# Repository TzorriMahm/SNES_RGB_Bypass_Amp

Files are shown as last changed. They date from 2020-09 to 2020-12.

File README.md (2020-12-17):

# SNES RGB Bypass Amp
**A modding board to bypass the SNES' video encoder by using TI's THS7374 video amplifier, to achieve optimised RGB video.**<br>

This modification works with all 1-Chip models (PAL/NTSC).

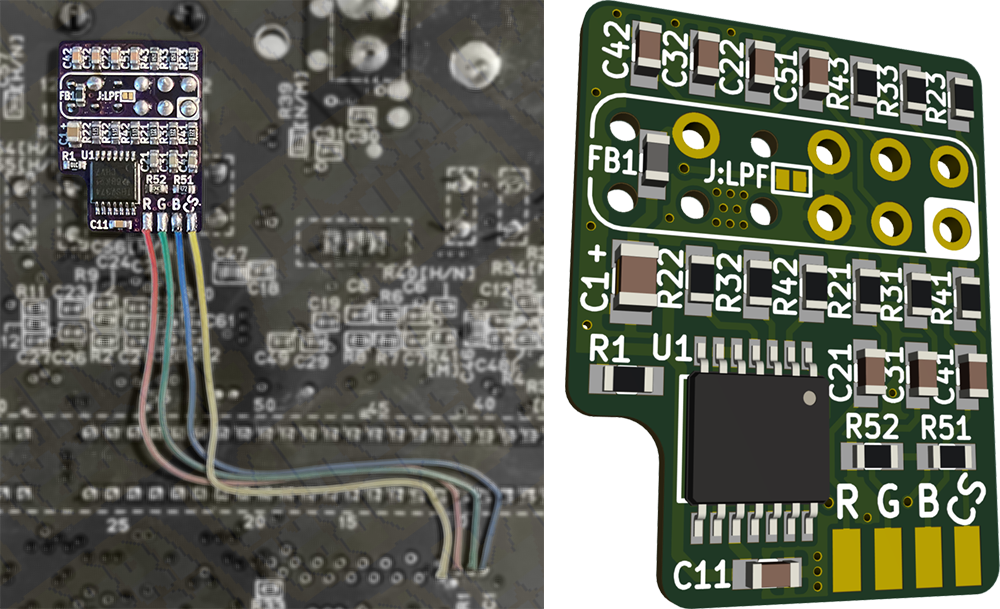
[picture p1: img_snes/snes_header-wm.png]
Header image

<br><br>
**⁓ Designed with ♥ in Germany ⁓**<br><br>
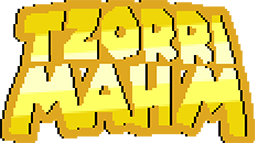
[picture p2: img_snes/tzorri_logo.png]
TzorriMahm

# Where to get the PCB?
You can order the PCB directly from [OSHPark](https://oshpark.com/shared_projects/o16zk0W4).
Of course, feel free to use the gerber files with any manufacturer of your choice.<br>
Use 0.8mm board thickness to ensure an easy and clean installation.

# Before you start
Make sure that your console is a 1-Chip model. If your console is a SNES2/Mini/Jr., this is the case by default.<br>
Otherwise, this can easily done by looking for an indicator at the main board:

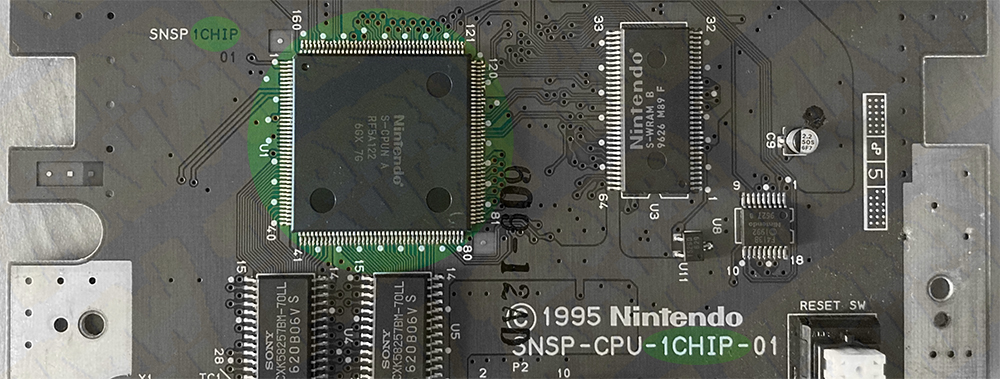
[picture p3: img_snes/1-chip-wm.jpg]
1-CHIP


# Install instructions
## PAL consoles (SNSP-001)
### Preparing the SNES main board
**1-CHIP-01/02 models**
- disconnect +12V from MultiOut Pin 3: **remove R28**
- disconnect stock RGB: **remove R15, R16, R17**
- remove decoupling caps from MultiOut (optional**¹**): **remove C44, C45, C46, C47**

### Installing the modding board
- isolate the bottom side of the modding board to avoid any shorts
- solder the modding board onto the pins of the MultiOut
- solder a wire from the via next to R6 (SNES main board) to pad 'R' (modding board)
- solder a wire from the via next to R7 (SNES main board) to pad 'G' (modding board)
- solder a wire from the via next to R8 (SNES main board) to pad 'B' (modding board)  
- solder a wire from the via that is nearest the bottom left corner of designator C6 (SNES main board) to pad 'CS' (modding board)  

### Install diagram (PAL 1-CHIP)
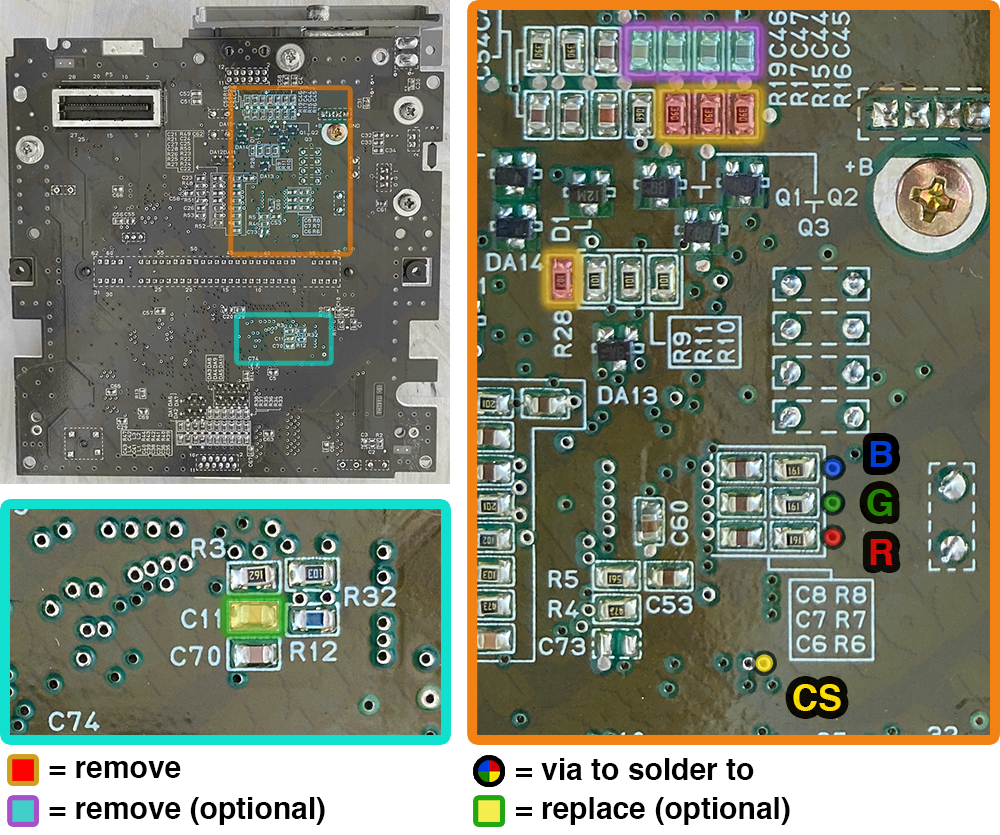
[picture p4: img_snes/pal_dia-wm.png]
PAL install diagram


## NTSC consoles (SNS-001/SHVC-001)
### Preparing the SNES main board
**1-CHIP-01/02 models**<br>
These models already have C-Sync connected to pin 3 of the MultiOut.<br>
You can either use this (not recommended) or:
- disconnect C-Sync from MultiOut Pin 3: **remove R12** (optionally **remove R9, R10, R11, Q1** as well)
- disconnect stock RGB: **remove R15, R16, R17**
- remove decoupling caps from MultiOut (optional**¹**): **remove C44, C45, C46, C47**

**1-CHIP-03 model**<br>
This model hasn't C-Sync connected at all, so you'll have nothing to do here.
- disconnect stock RGB:	**remove R15, R16, R17**
- remove decoupling caps from MultiOut (optional**¹**'**²**):	**remove C44, C45, C47**

### Installing the modding board
- isolate the bottom side of the modding board to avoid any shorts
- solder the modding board onto the pins of the MultiOut
- solder a wire from the via next to R6 (SNES main board) to pad 'R' (modding board)
- solder a wire from the via next to R7 (SNES main board) to pad 'G' (modding board)
- solder a wire from the via next to R8 (SNES main board) to pad 'B' (modding board) 
- solder a wire from the via under the left pad of R9 (SNES main board) to pad 'CS' (modding board)

### Install diagram (NTSC 1-CHIP)
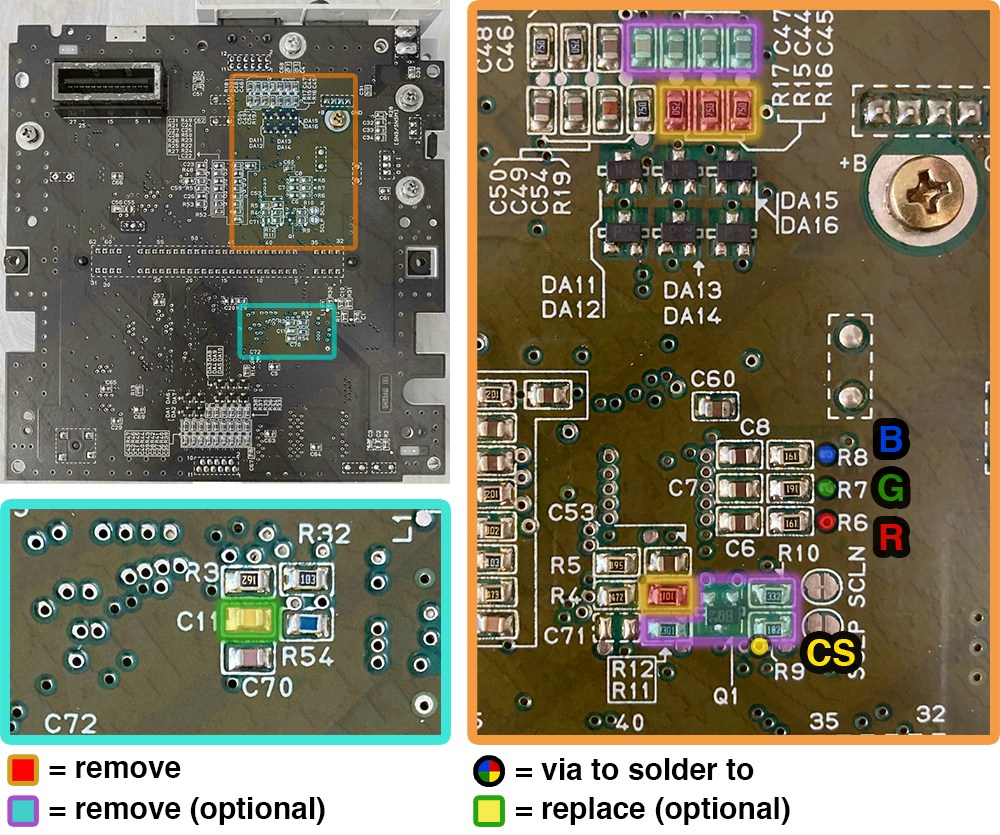
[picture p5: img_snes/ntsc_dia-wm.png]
NTSC install diagram


## NTSC model 2 / SNES2/Mini/Jr. (SNS-101/SHVC-101)
### Preparing the SNES main board
**SNN-CPU-01 model**<br>
Since this model doesn't have stock RGB, here is no preparation needed.

### Installing the modding board
- isolate the bottom side of the modding board to avoid any shorts
- solder the modding board onto the pins of the MultiOut
- solder wires from the vias (shown in the install diagram below) to the appropriate pads on the modding board

### Install diagram (SNES2/Mini/Jr.)
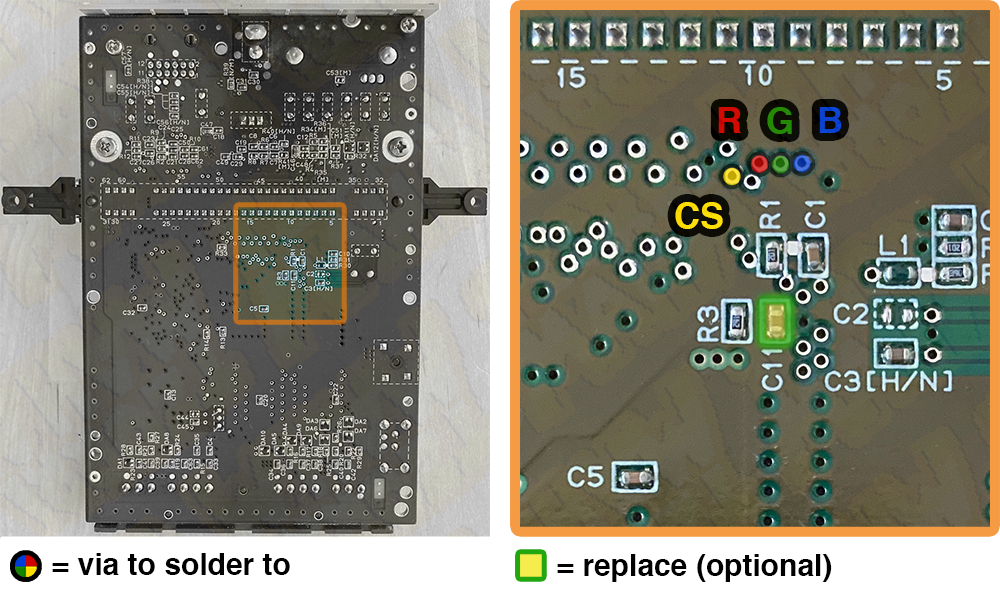
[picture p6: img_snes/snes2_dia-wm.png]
SNES2 install diagram


### Notes
**¹** if you remove the decoupling caps at the MultiOut, make sure to occupy C22, C32, C42 & C51 on the modding board! Never use both at the same time!<br>
**²** if you leave the decoupling caps at the MultiOut, make sure to occupy **at least** C51 on the modding board! (1-CHIP-03 only!) 

# Troubleshooting
Double-check continuity between connections:
- 'R' (modding board) ⇄ S-CPUN pin 156 / S-RGB pin 5 (SNES main board)
- 'G' (modding board) ⇄ S-CPUN pin 157 / S-RGB pin 3 (SNES main board)
- 'B' (modding board) ⇄ S-CPUN pin 158 / S-RGB pin 1 (SNES main board)
- 'CS' (modding board) ⇄ S-CPUN pin 151 / S-RGB pin 7 (SNES main board)

# Miscellaneous
#### Jumper 'J:LPF'
The THS7374 has a low pass filter on each of the four channels which can be turned on by shorting jumper 'J:LPF' on the modding board. This is mostly needed if you wire the console directly to a flat-screen TV. There's no need for the low pass filter on analogue devices.<br>
If you use an OSSC or a Framemeister, it's better to use their filter options.

#### Ghosting fix
In order to get rid of the ghosting issue (which 1-Chip models are known for), simply replace C11 (SNES main board) by a 470nF ceramic capacitor (0805 for normal/fat models, 0603 for SNES2/Mini/Jr.).

#### RGB cable
You will need a RGB cable with 220µF electrolytic capacitors on each of the 'R', 'G' & 'B' lines. The positive end is facing towards the console.<br>
This modding board is designed to output TTL level C-Sync directly at the MultiOut of the console.<br>
With that in mind, make sure you're using a suitable cable with a 470Ω resistor on the sync line to use it with most consumer products (like TV's, OSSC, Framemeister)!

# Disclaimer
I am not responsible for any damage to you, your devices or anything else!<br>
If you do the modification, you do it at your own risk and responsibility!

# Acknowledgement
Most of the credits should go to [borti4938](https://github.com/borti4938). He has made the actual (slightly different) circuit and inspired me to design this board. Thanks man! Thanks to Voultar for research and findig the ghosting fix! Thanks Bob, for your awesome and informative website [RetroRGB](http://retrorgb.com)!<br>
And of course, thanks to the whole retro gaming community for keeping the spirit alive!

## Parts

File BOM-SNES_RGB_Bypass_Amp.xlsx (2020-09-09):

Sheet: Normal, fat model
SNES RGB Bypass Amp - Bill of Materials
for normal/fat models
Designator | Mfr. No | Quantity | Description | Package | Value | Mouser
U1 | THS7374IPWR | 1 | 4-Ch. SD Video Amp | TSSOP-14 |  | https://www.mouser.de/ProductDetail/Texas-Instruments/THS7374IPWR?qs=qU0TI%2FZyA%252BxCw%252BZ%2FnXjpBw%3D%3D
C1 | 08053D226MAT2A | 1 | Ceramic capacitor; X5R; 25V | SMD0805 | 22µF / 20% | https://www.mouser.de/ProductDetail/AVX/08053D226MAT2A?qs=bxXxiBiblXqtZp79ClJbtg%3D%3D
C11 | 06035C104KAT2A | 1 | Ceramic capacitor; X7R; 50V | SMD0603 | 100nF / 10% | https://www.mouser.de/ProductDetail/AVX/06035C104KAT2A?qs=wORnlwVG%2F0dQ8Y%2FnMEnCGg%3D%3D
C21, C31, C31 | 0603YC823KAT2A | 3 | Ceramic capacitor; X7R; 16V | SMD0603 | 82nF / 10% | https://www.mouser.de/ProductDetail/AVX/0603YC823KAT2A?qs=Gc704lYbI0w4J5zALMwFzw%3D%3D
C22, C32, C42, C51 | 0603YC470KAT2A | 4 | Ceramic capacitor; X7R, 16V | SMD0603 | 47pF / 10% | https://www.mouser.de/ProductDetail/AVX/0603YC470KAT2A?qs=EU6FO9ffTwcFkDrBSOUNAw%3D%3D
FB1 | MPZ1608S221ATA00 | 1 | Ferrite bead; power line | SMD0603 |  | https://www.mouser.de/ProductDetail/TDK/MPZ1608S221ATA00
R1 | RC0603FR-0710KL | 1 | Resistor; 1/10W | SMD0603 | 10kΩ / 1% | https://www.mouser.de/ProductDetail/Yageo/RC0603FR-0710KL?qs=grNVn54RoB%252B3GtjbJj3wJQ%3D%3D
R21, R31, R41 | RC0603FR-07750RL | 3 | Resistor; 1/10W | SMD0603 | 750Ω / 1% | https://www.mouser.de/ProductDetail/Yageo/RC0603FR-07750RL?qs=FHALIGSka6kXmIWmb0xdTA%3D%3D
R22, R32, R42 | RC0603FR-075M1L | 3 | Resistor; 1/10W | SMD0603 | 5.1MΩ / 1% | https://www.mouser.de/ProductDetail/Yageo/RC0603FR-075M1L
R23, R33, R43 | RC0603FR-0775RL | 3 | Resistor; 1/10W | SMD0603 | 75Ω / 1% | https://www.mouser.de/ProductDetail/Yageo/RC0603FR-0775RL
R51 | RC0603FR-074K99L | 1 | Resistor; 1/10W | SMD0603 | 4.99kΩ / 1% | https://www.mouser.de/ProductDetail/Yageo/RC0603FR-074K99L
R52 | RC0603FR-074K3L | 1 | Resistor; 1/10W | SMD0603 | 4.3kΩ / 1% | https://www.mouser.de/ProductDetail/Yageo/RC0603FR-074K3L
Mouser Basket: | https://www.mouser.de/ProjectManager/ProjectDetail.aspx?AccessID=b03722a6a4

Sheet: Normal, fat model + DeJitter
SNES RGB Bypass Amp - Bill of Materials
for normal/fat models with DeJitter mod installed
Designator | Mfr. No | Quantity | Description | Package | Value | Mouser
U1 | THS7374IPWR | 1 | 4-Ch. SD Video Amp | TSSOP-14 |  | https://www.mouser.de/ProductDetail/Texas-Instruments/THS7374IPWR?qs=qU0TI%2FZyA%252BxCw%252BZ%2FnXjpBw%3D%3D
C1 | 08053D226MAT2A | 1 | Ceramic capacitor; X5R; 25V | SMD0805 | 22µF / 20% | https://www.mouser.de/ProductDetail/AVX/08053D226MAT2A?qs=bxXxiBiblXqtZp79ClJbtg%3D%3D
C11 | 06035C104KAT2A | 1 | Ceramic capacitor; X7R; 50V | SMD0603 | 100nF / 10% | https://www.mouser.de/ProductDetail/AVX/06035C104KAT2A?qs=wORnlwVG%2F0dQ8Y%2FnMEnCGg%3D%3D
C21, C31, C31 | 0603YC823KAT2A | 3 | Ceramic capacitor; X7R; 16V | SMD0603 | 82nF / 10% | https://www.mouser.de/ProductDetail/AVX/0603YC823KAT2A?qs=Gc704lYbI0w4J5zALMwFzw%3D%3D
C22, C32, C42, C51 | 0603YC470KAT2A | 4 | Ceramic capacitor; X7R, 16V | SMD0603 | 47pF / 10% | https://www.mouser.de/ProductDetail/AVX/0603YC470KAT2A?qs=EU6FO9ffTwcFkDrBSOUNAw%3D%3D
FB1 | MPZ1608S221ATA00 | 1 | Ferrite bead; power line | SMD0603 |  | https://www.mouser.de/ProductDetail/TDK/MPZ1608S221ATA00
R1 | RC0603FR-0710KL | 1 | Resistor; 1/10W | SMD0603 | 10kΩ / 1% | https://www.mouser.de/ProductDetail/Yageo/RC0603FR-0710KL?qs=grNVn54RoB%252B3GtjbJj3wJQ%3D%3D
R21, R31, R41 | RC0603FR-07750RL | 3 | Resistor; 1/10W | SMD0603 | 750Ω / 1% | https://www.mouser.de/ProductDetail/Yageo/RC0603FR-07750RL?qs=FHALIGSka6kXmIWmb0xdTA%3D%3D
R22, R32, R42 | RC0603FR-075M1L | 3 | Resistor; 1/10W | SMD0603 | 5.1MΩ / 1% | https://www.mouser.de/ProductDetail/Yageo/RC0603FR-075M1L
R23, R33, R43 | RC0603FR-0775RL | 3 | Resistor; 1/10W | SMD0603 | 75Ω / 1% | https://www.mouser.de/ProductDetail/Yageo/RC0603FR-0775RL
R51 | RC0603FR-074K7L | 1 | Resistor; 1/10W | SMD0603 | 4.7kΩ / 1% | https://www.mouser.de/ProductDetail/Yageo/RC0603FR-074K7L
R52 | RC0603FR-0710K7L | 1 | Resistor; 1/10W | SMD0603 | 10.7kΩ / 1% | https://www.mouser.de/ProductDetail/Yageo/RC0603FR-0710K7L
Mouser Basket | https://www.mouser.de/ProjectManager/ProjectDetail.aspx?AccessID=d139a54297

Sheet: SNES2-Mini-Jr.
SNES RGB Bypass Amp - Bill of Materials
for SNES2/Mini/Jr. model
Designator | Mfr. No | Quantity | Description | Package | Value | Mouser
U1 | THS7374IPWR | 1 | 4-Ch. SD Video Amp | TSSOP-14 |  | https://www.mouser.de/ProductDetail/Texas-Instruments/THS7374IPWR?qs=qU0TI%2FZyA%252BxCw%252BZ%2FnXjpBw%3D%3D
C1 | 08053D226MAT2A | 1 | Ceramic capacitor; X5R; 25V | SMD0805 | 22µF / 20% | https://www.mouser.de/ProductDetail/AVX/08053D226MAT2A?qs=bxXxiBiblXqtZp79ClJbtg%3D%3D
C11 | 06035C104KAT2A | 1 | Ceramic capacitor; X7R; 50V | SMD0603 | 100nF / 10% | https://www.mouser.de/ProductDetail/AVX/06035C104KAT2A?qs=wORnlwVG%2F0dQ8Y%2FnMEnCGg%3D%3D
C21, C31, C31 | 0603YC823KAT2A | 3 | Ceramic capacitor; X7R; 16V | SMD0603 | 82nF / 10% | https://www.mouser.de/ProductDetail/AVX/0603YC823KAT2A?qs=Gc704lYbI0w4J5zALMwFzw%3D%3D
C22, C32, C42, C51 | 0603YC470KAT2A | 4 | Ceramic capacitor; X7R, 16V | SMD0603 | 47pF / 10% | https://www.mouser.de/ProductDetail/AVX/0603YC470KAT2A?qs=EU6FO9ffTwcFkDrBSOUNAw%3D%3D
FB1 | MPZ1608S221ATA00 | 1 | Ferrite bead; power line | SMD0603 |  | https://www.mouser.de/ProductDetail/TDK/MPZ1608S221ATA00
R1 | RC0603FR-0710KL | 1 | Resistor; 1/10W | SMD0603 | 10kΩ / 1% | https://www.mouser.de/ProductDetail/Yageo/RC0603FR-0710KL?qs=grNVn54RoB%252B3GtjbJj3wJQ%3D%3D
R21, R31, R41 | RC0603FR-071K2L | 3 | Resistor; 1/10W | SMD0603 | 1.2kΩ / 1% | https://www.mouser.de/ProductDetail/Yageo/RC0603FR-071K2L?qs=VU8sRB4EgwBLEnKW6KYjqA%3D%3D
R22, R32, R42 | RC0603FR-075M1L | 3 | Resistor; 1/10W | SMD0603 | 5.1MΩ / 1% | https://www.mouser.de/ProductDetail/Yageo/RC0603FR-075M1L
R23, R33, R43 | RC0603FR-0775RL | 3 | Resistor; 1/10W | SMD0603 | 75Ω / 1% | https://www.mouser.de/ProductDetail/Yageo/RC0603FR-0775RL
R51 | RC0603FR-074K99L | 1 | Resistor; 1/10W | SMD0603 | 4.99kΩ / 1% | https://www.mouser.de/ProductDetail/Yageo/RC0603FR-074K99L
R52 | RC0603FR-074K3L | 1 | Resistor; 1/10W | SMD0603 | 4.3kΩ / 1% | https://www.mouser.de/ProductDetail/Yageo/RC0603FR-074K3L
Mouser Basket: | https://www.mouser.de/ProjectManager/ProjectDetail.aspx?AccessID=137eea1f68

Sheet: SNES2-Mini-Jr. + DeJitter
SNES RGB Bypass Amp - Bill of Materials
for SNES2/Mini/Jr. model with DeJitter mod installed
Designator | Mfr. No | Quantity | Description | Package | Value | Mouser
U1 | THS7374IPWR | 1 | 4-Ch. SD Video Amp | TSSOP-14 |  | https://www.mouser.de/ProductDetail/Texas-Instruments/THS7374IPWR?qs=qU0TI%2FZyA%252BxCw%252BZ%2FnXjpBw%3D%3D
C1 | 08053D226MAT2A | 1 | Ceramic capacitor; X5R; 25V | SMD0805 | 22µF / 20% | https://www.mouser.de/ProductDetail/AVX/08053D226MAT2A?qs=bxXxiBiblXqtZp79ClJbtg%3D%3D
C11 | 06035C104KAT2A | 1 | Ceramic capacitor; X7R; 50V | SMD0603 | 100nF / 10% | https://www.mouser.de/ProductDetail/AVX/06035C104KAT2A?qs=wORnlwVG%2F0dQ8Y%2FnMEnCGg%3D%3D
C21, C31, C31 | 0603YC823KAT2A | 3 | Ceramic capacitor; X7R; 16V | SMD0603 | 82nF / 10% | https://www.mouser.de/ProductDetail/AVX/0603YC823KAT2A?qs=Gc704lYbI0w4J5zALMwFzw%3D%3D
C22, C32, C42, C51 | 0603YC470KAT2A | 4 | Ceramic capacitor; X7R, 16V | SMD0603 | 47pF / 10% | https://www.mouser.de/ProductDetail/AVX/0603YC470KAT2A?qs=EU6FO9ffTwcFkDrBSOUNAw%3D%3D
FB1 | MPZ1608S221ATA00 | 1 | Ferrite bead; power line | SMD0603 |  | https://www.mouser.de/ProductDetail/TDK/MPZ1608S221ATA00
R1 | RC0603FR-0710KL | 1 | Resistor; 1/10W | SMD0603 | 10kΩ / 1% | https://www.mouser.de/ProductDetail/Yageo/RC0603FR-0710KL?qs=grNVn54RoB%252B3GtjbJj3wJQ%3D%3D
R21, R31, R41 | RC0603FR-071K2L | 3 | Resistor; 1/10W | SMD0603 | 1.2kΩ / 1% | https://www.mouser.de/ProductDetail/Yageo/RC0603FR-071K2L?qs=VU8sRB4EgwBLEnKW6KYjqA%3D%3D
R22, R32, R42 | RC0603FR-075M1L | 3 | Resistor; 1/10W | SMD0603 | 5.1MΩ / 1% | https://www.mouser.de/ProductDetail/Yageo/RC0603FR-075M1L
R23, R33, R43 | RC0603FR-0775RL | 3 | Resistor; 1/10W | SMD0603 | 75Ω / 1% | https://www.mouser.de/ProductDetail/Yageo/RC0603FR-0775RL
R51 | RC0603FR-074K7L | 1 | Resistor; 1/10W | SMD0603 | 4.7kΩ / 1% | https://www.mouser.de/ProductDetail/Yageo/RC0603FR-074K7L
R52 | RC0603FR-0710K7L | 1 | Resistor; 1/10W | SMD0603 | 10.7kΩ / 1% | https://www.mouser.de/ProductDetail/Yageo/RC0603FR-0710K7L
Mouser Basket: | https://www.mouser.de/ProjectManager/ProjectDetail.aspx?AccessID=aa5ca245f8

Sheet: Ghosting fix
Ghosting fix (optional)
(replace capacitor on SNES main board)
Designator (SNES) | Mfr. No | Quantity | Description | Package | Value | Note | Mouser
C11 | 0805YC474KAT2A | 1 | Ceramic capacitor; X7R, 16V | SMD0805 | 470nF / 10% | for normal/fat model | https://www.mouser.de/ProductDetail/AVX/0805YC474KAT2A?qs=x%2FgdHuCDerNY43ALHLz9VA%3D%3D
C11 | 0603YC474KAT2A | 1 | Ceramic capacitor; X7R, 16V | SMD0603 | 470nF / 10% | for SNES2/Mini/Jr. | https://www.mouser.de/ProductDetail/AVX/0603YC474KAT2A

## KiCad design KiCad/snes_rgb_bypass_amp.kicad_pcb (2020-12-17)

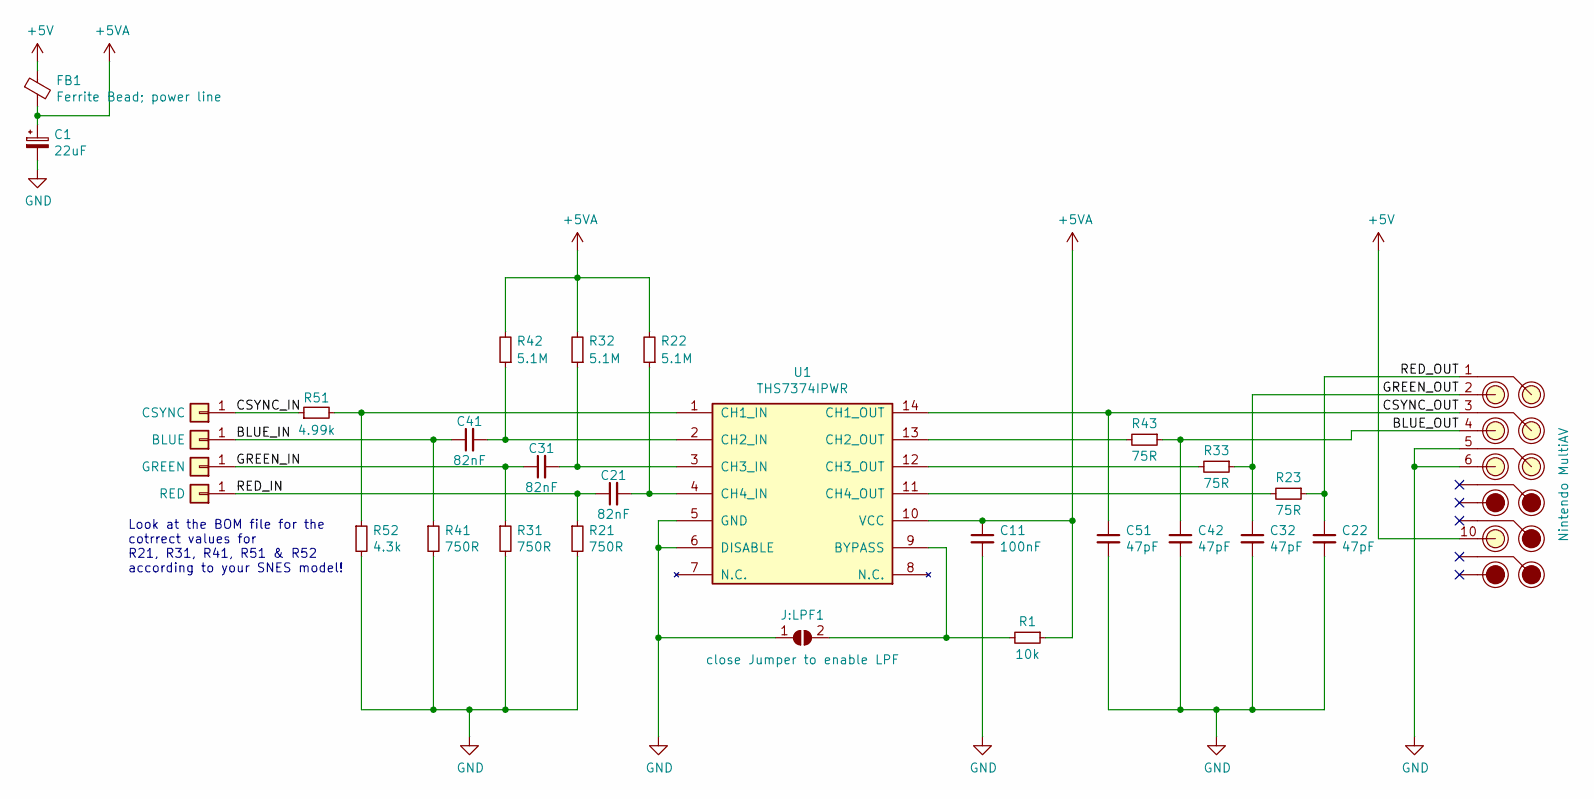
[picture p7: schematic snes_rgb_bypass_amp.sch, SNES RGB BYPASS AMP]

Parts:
C1: 22uF; C_SMD0805
C11: 100nF; C_SMD0603
C21, C31, C41: 82nF; C_SMD0603
C22, C32, C42, C51: 47pF; C_SMD0603
FB1: Ferrite Bead; power line; FB_SMD0603
INPUT_1: RED; SolderPad_customizable
INPUT_2: GREEN; SolderPad_customizable
INPUT_3: BLUE; SolderPad_customizable
INPUT_4: CSYNC; SolderPad_customizable
J:LPF1: close Jumper to enable LPF; SolderJumper_2x0.5x0.75mm
MultiAV1: Nintendo MultiAV; NintendoMultiAV_FB-gap
R1: 10k; R_SMD0603
R21, R31, R41: 750R; R_SMD0603
R22, R32, R42: 5.1M; R_SMD0603
R23, R33, R43: 75R; R_SMD0603
R51: 4.99k; R_SMD0603
R52: 4.3k; R_SMD0603
U1: THS7374IPWR; TSSOP-14

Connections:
+5V: FB1.1, MultiAV1.10
+5VA: C1.1, C11.1, FB1.2, R1.1, R22.2, R32.2, R42.2, U1.10 (VCC)
/BLUE_IN: C41.1, INPUT_3.1, R41.1
/BLUE_OUT: C42.1, MultiAV1.4, R43.1
/CSYNC_IN: INPUT_4.1, R51.1
/CSYNC_OUT: C51.1, MultiAV1.3, U1.14 (CH1_OUT)
/GREEN_IN: C31.1, INPUT_2.1, R31.1
/GREEN_OUT: C32.1, MultiAV1.2, R33.1
/RED_IN: C21.1, INPUT_1.1, R21.1
/RED_OUT: C22.1, MultiAV1.1, R23.1
GND: C1.2, C11.2, C22.2, C32.2, C42.2, C51.2, J:LPF1.1 (A), MultiAV1.5, MultiAV1.6, R21.2, R31.2, R41.2, R52.2, U1.5 (GND), U1.6 (DISABLE)
unnamed: C21.2, R22.1, U1.4 (CH4_IN)
unnamed: C31.2, R32.1, U1.3 (CH3_IN)
unnamed: C41.2, R42.1, U1.2 (CH2_IN)
unnamed: J:LPF1.2 (B), R1.2, U1.9 (BYPASS)
unnamed: R23.2, U1.11 (CH4_OUT)
unnamed: R33.2, U1.12 (CH3_OUT)
unnamed: R43.2, U1.13 (CH2_OUT)
unnamed: R51.2, R52.1, U1.1 (CH1_IN)

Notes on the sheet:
Look at the BOM file for the cotrrect values for R21, R31, R41, R51 & R52 according to your SNES model!

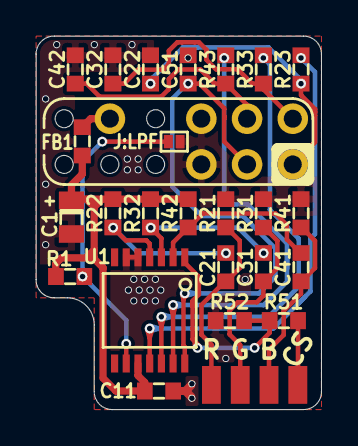
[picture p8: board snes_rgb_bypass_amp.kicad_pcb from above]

Board: 2 copper layers, 15.9 x 20.8 mm, 30 parts (1 on the bottom side), 19 nets.

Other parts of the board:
***: TM_logo-silk

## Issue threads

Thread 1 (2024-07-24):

Brightness Fix

King007t, 2024-07-24:
Does this board do the brightness fix on its own, or di I still have to replace the R3 resistor.
And do I have to use CS ttl (cs.o raw) or CS 75 ohm (cs.o buff) from an super cic++ board.

Best regards

TzorriMahm, 2024-07-25:
Yes, brightness fix is included. No need to change the value of R3.
You should use "CS.o raw" on borti's MultiRegion Mod and connect it to the "CS" Pad on the RGB amp.
Furthermore you don't have to lift Pin 7 of the SNES' S-RGB IC because you will completely bypass it.

King007t, 2024-07-25:
Hi, i already changed the resistor with a 1.74kOhm resistor. Now the image is too dark. What was the original value so i can change it back?

TzorriMahm, 2024-07-25:
Original value of R3 is 1.6k.
You could also remove R21, R31 and R41 on the amp instead.

King007t, 2024-07-25:
The resistors arent there anyways. Its still to dim compared to my snes 3 chip

TzorriMahm, 2024-07-25:
If R21/R31/R41 aren't populated you should swap R3 again.

Are you using an RGB cable suitable for NTSC consoles?

King007t, 2024-07-25:
So currently r3 is swapped to 1.74kOhm and the the 3 on the pcb arend populated. And somehow its a bit dimmer than original

TzorriMahm, 2024-07-25:
That's correct.

And what kind of RGB cable do you use?

King007t, 2024-07-25:
Its a attenuated csync ntsc from retrogamingcables. The one from the 3 chip is a sync on luma pal cable

King007t, 2024-07-25:
Hmm okay. I took some screenshots
SNES 1 chip: CSync
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
SNES 3 chip: Sync on Luma
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

can this be because of sync on luma

King007t, 2024-07-25:
And I remember my ebay seller told me to change R51 on your RGB Bypass AMP to 4.7k and R52 to 10.7k if i use dejitter, which i am doing. Could this change have maybe affected this? And was information even correct?

TzorriMahm, 2024-07-25:
It's indeed dimmer than the 3-chip.
Changing values of R51 and R52 is correct when using de-jittered sync.

Closed 2024-07-25.

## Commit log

2020-12-17 Add KiCad files for v3.2
    - project file
    - schematics
    - design file
    - libraries
    [snes_rgb_bypass_amp.kicad_pcb, snes_rgb_bypass_amp.sch]
2020-12-17 Replace gerber files to match v3.2
    [SNES RGB BYPASS AMP v3.1-B_Mask.gbs, SNES RGB BYPASS AMP v3.1-B_SilkS.gbo, SNES RGB BYPASS AMP v3.1-Component.gtl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]
2020-12-17 minor fix of bottom silk screen
    [snes_rgb_bypass_amp.kicad_pcb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]
